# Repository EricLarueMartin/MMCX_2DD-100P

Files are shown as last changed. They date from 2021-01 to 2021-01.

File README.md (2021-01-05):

# MMCX_2DD-100P
Adapter between MMCX connectors to a 2DD 100 pin connector for Gretina cards

Requires two PCBs on 47 mil board, one for even channel and one for odd channels.
MMCX_2DD-100P_Even.zip and MMCX_2DD-100P_Odd.zip

Uses MMCX connectors: MOLEX 0734150961

The other connector is a double density 100 pin DSub connector: ITT Cannon 2DD-100PF0

The pins for the connector are 031-9540-015

Any MMCX plug can connector to the adapter, such as MOLEX 0734150970

The connector housing is in three pieces, two half shells and a spacer that goes between them. 
The two half shells are made of two material so that channel labels and the UNC logo are visible. This is all contained in: HousingLogoLabeled.2mf

The boards will be mounted at and angle, and the pins need to be soldered on first. A jig is recommended to insert the board without bending the pins:
InsertionGuideA.stl and InsertionGuideB.stl

To solder the pins in the correct position a connector with the holes drilled so the pins don't get stuck was used previously. Printing a jig for the pins from 2DD-100P.ipt should also work, but verify the hole spacing first as I think it was slightly off.

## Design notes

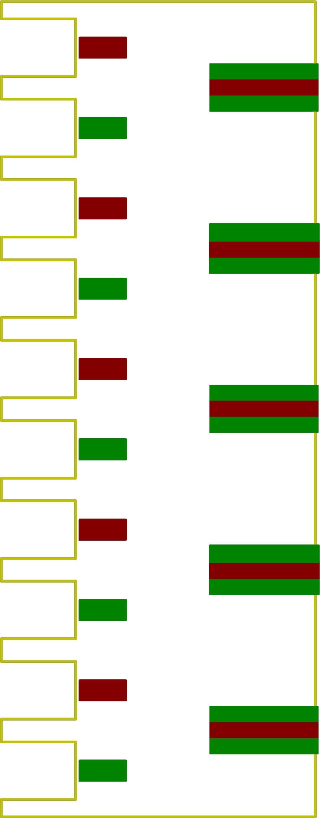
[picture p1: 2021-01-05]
MMCX_2DD-100P_Odd.png

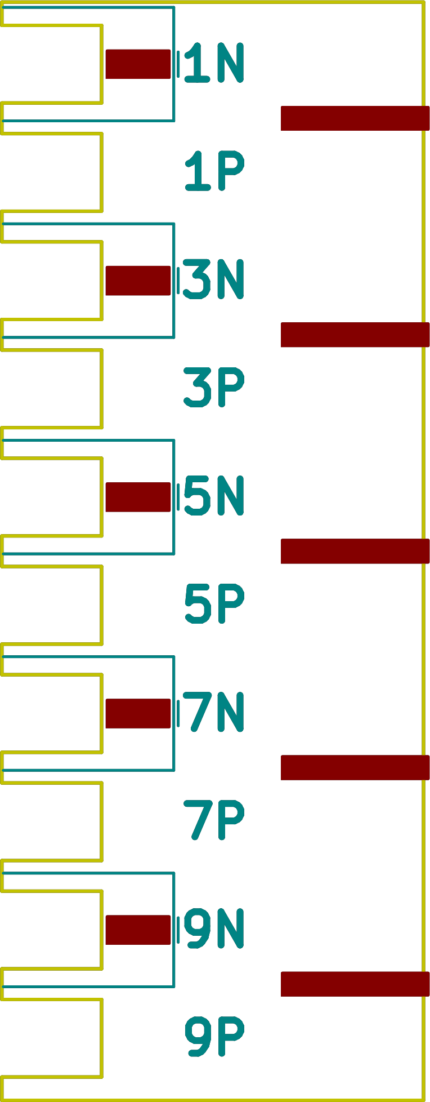
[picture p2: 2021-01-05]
MMCX_2DD-100P_Odd_Front.png

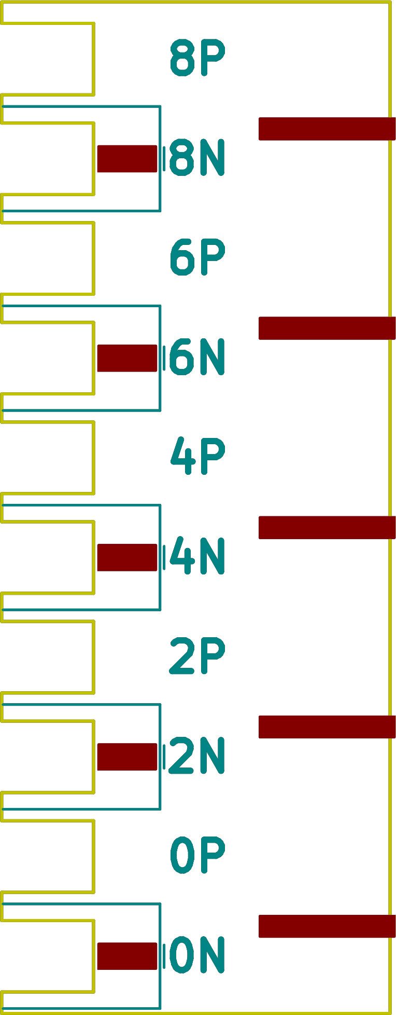
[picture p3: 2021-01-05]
MMCX_2DD-100P_Even_Front.png

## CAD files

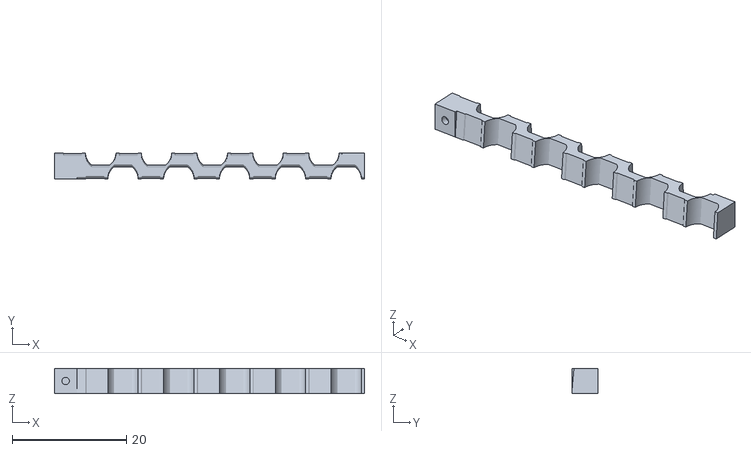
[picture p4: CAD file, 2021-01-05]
HousingSpacer.stl
54.2 x 4.63 x 4.41

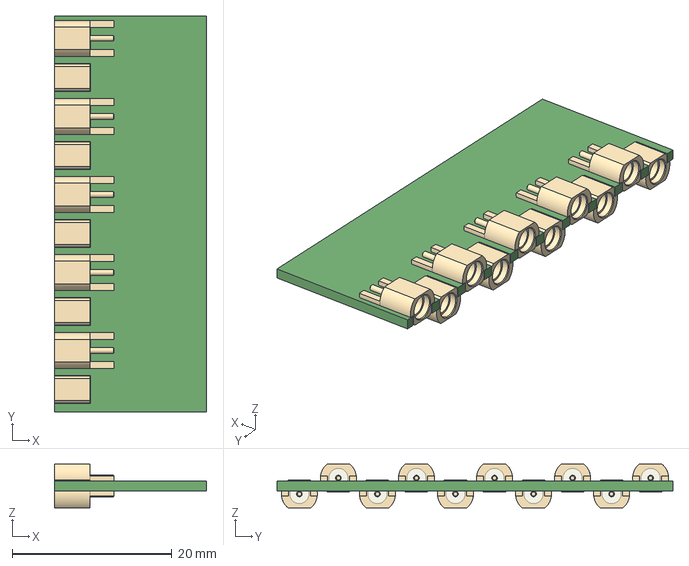
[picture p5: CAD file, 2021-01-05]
MMCX_2DD-100P_Odd.step
19.0 x 49.5 x 5.49 mm

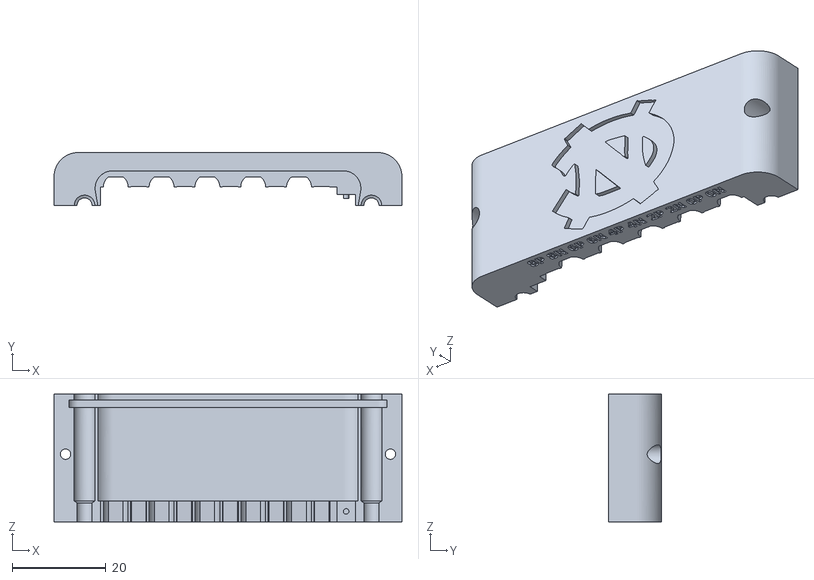
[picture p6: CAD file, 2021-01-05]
HousingEvenLogoLabeled.stl
74.1 x 11.3 x 27.2

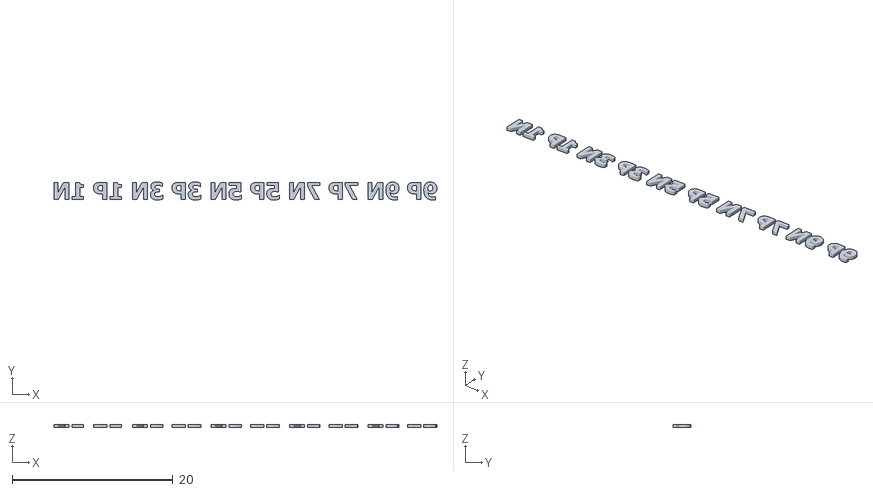
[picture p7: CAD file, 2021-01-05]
HousingOddLabels.stl
47.6 x 2.25 x 0.4

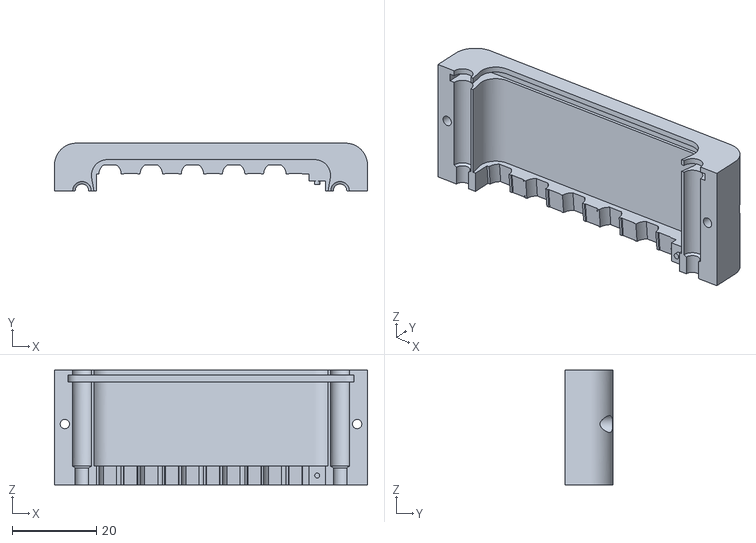
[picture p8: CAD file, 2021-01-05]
HousingBLogo.stl
74.1 x 11.3 x 27.2

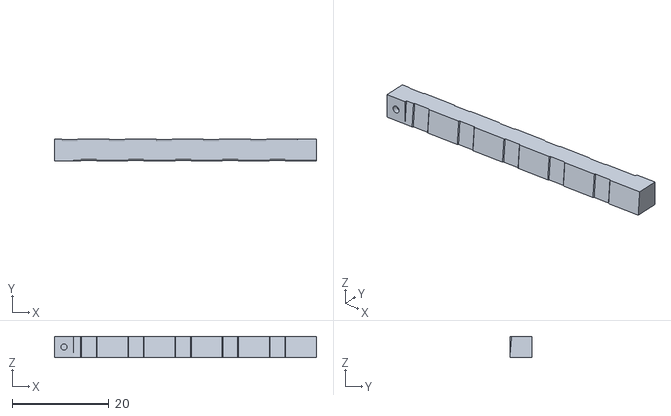
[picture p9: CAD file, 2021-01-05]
HousingSingleEndedALogo.stl
54.2 x 4.63 x 4.41

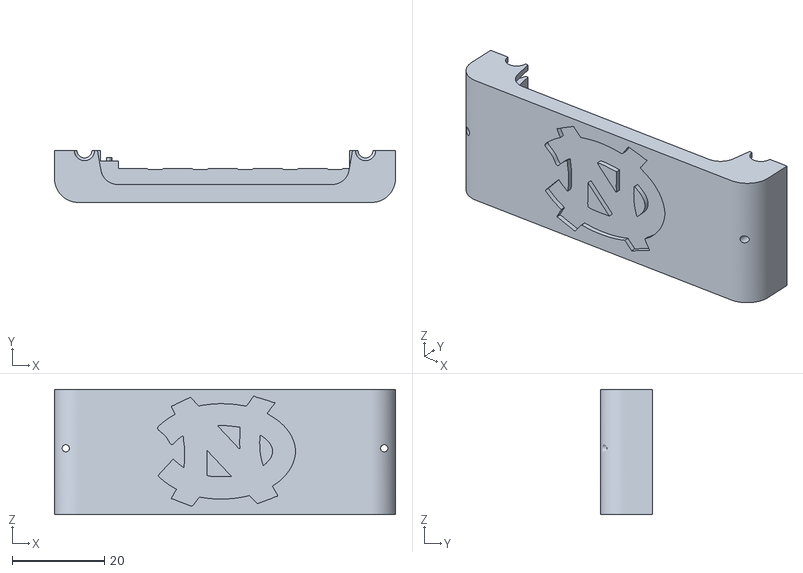
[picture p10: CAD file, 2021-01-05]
HousingSingleEndedCLogo.stl
74.1 x 11.3 x 27.2

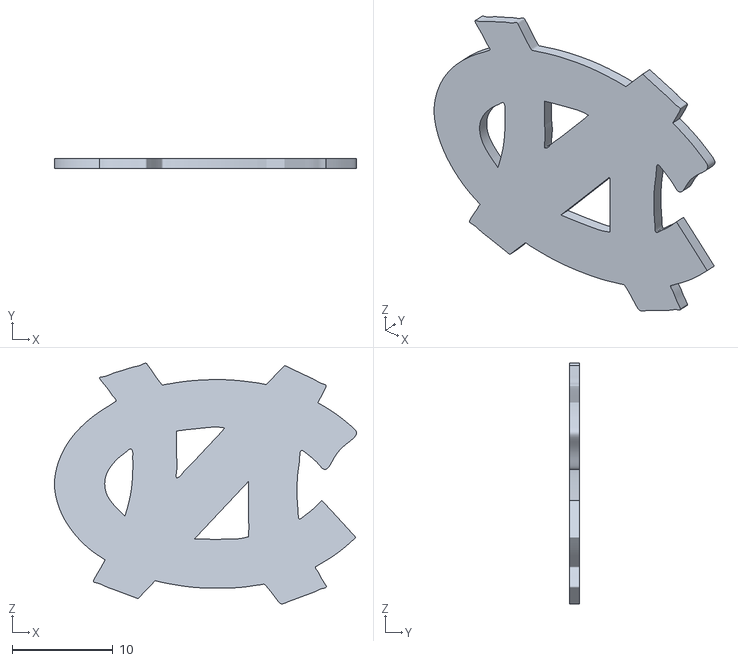
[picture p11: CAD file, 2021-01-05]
LogoB.stl
30.0 x 1.00 x 23.9

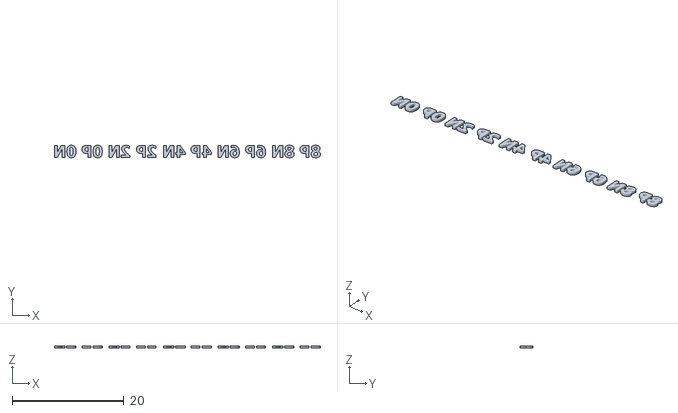
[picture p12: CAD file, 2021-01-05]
HousingEvenLabels.stl
47.6 x 2.26 x 0.4

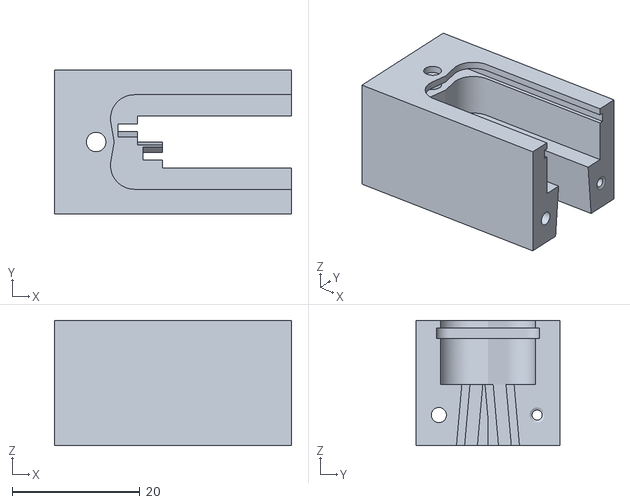
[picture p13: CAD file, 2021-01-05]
InsertionGuideB.stl
37.1 x 22.6 x 19.6

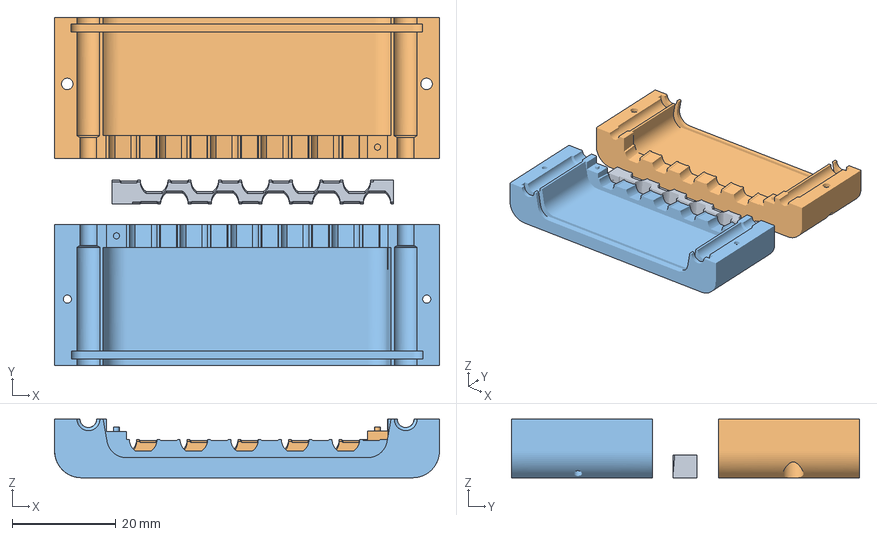
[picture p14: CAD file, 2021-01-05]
HousingLogoLabeled.3mf
74.2 x 67.0 x 11.3 mm
HousingSpacer.stl
HousingEvenLabels.stl
HousingOddLabels.stl

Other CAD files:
MMCX_2DD-100P_Even.step
HousingCLogo.stl
HousingA.stl
MMCX_2DD-100P.step
HousingSingleEndedBLogo.stl
HousingOddLogoLabeled.stl
InsertionGuideA.stl
2DD-100P.ipt
734151251.ipt
734151251.stp
HalfInterlockBox.ipt
HousingLabels.ipt
HousingLogo.ipt
HousingLogoPositive.ipt
HousingSingleEnded.ipt
HousingSingleEndedLogo.ipt
InsertionGuide.ipt
InsertionGuideOneConnected.ipt
LogoC.stl
MMCX_2DD-100P_All.iam
MMCX_2DD-100P_Even.iam
MMCX_2DD-100P_Guide.iam
MMCX_2DD-100P_Odd.iam
MMCX_Molex_73415-0961_Horizontal.iam
OldVersions/2DD-100P.0004.ipt
OldVersions/734151251.0001.ipt
OldVersions/Housing.0009.ipt
OldVersions/HousingLabels.0001.ipt
OldVersions/HousingLogo.0007.ipt
OldVersions/HousingLogoPositive.0002.ipt
OldVersions/HousingSingleEnded.0002.ipt
OldVersions/HousingSingleEndedLogo.0002.ipt
OldVersions/InsertionGuide.0003.ipt
OldVersions/MMCX_2DD-100P.0010.iam
OldVersions/MMCX_2DD-100P_All.0025.iam
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

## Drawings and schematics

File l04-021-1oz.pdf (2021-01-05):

## Multilayer PWB Construction Sheet

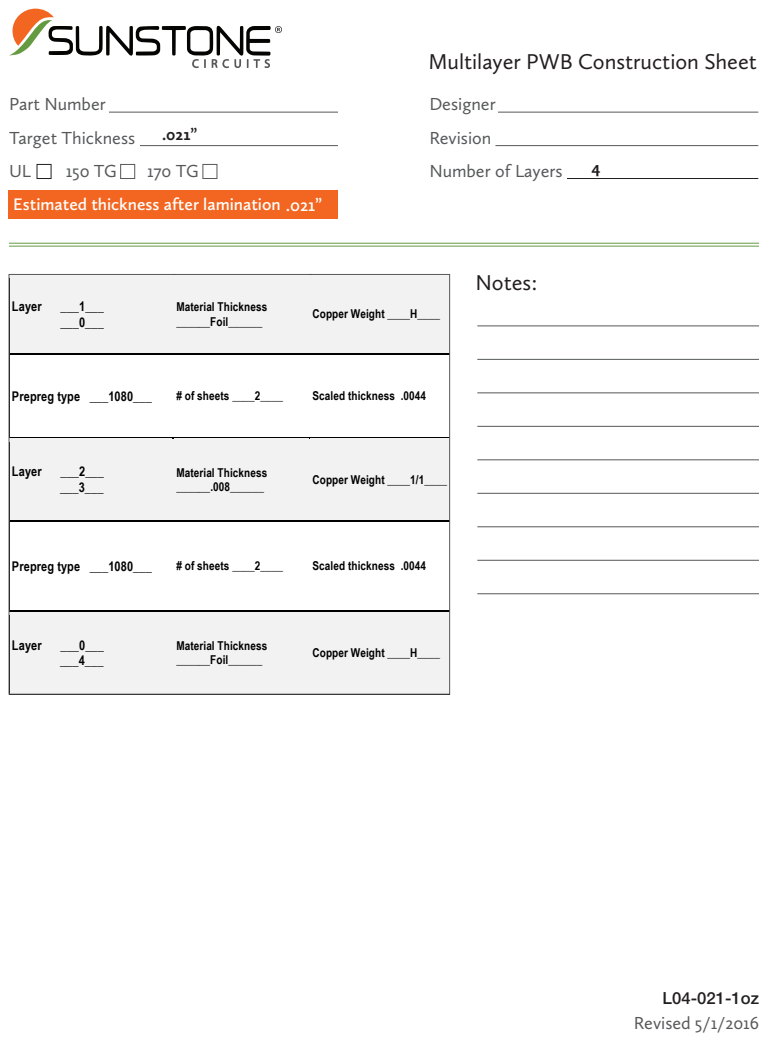
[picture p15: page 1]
Notes:; Revised 5/1/2016; Layer ___1___ ___0___; Material Thickness; ______Foil______; Copper Weight ____H____; Prepreg type ___1080___; # of sheets ____2____; Scaled thickness .0044; Layer ___2___ ___3___; Copper Weight ____1/1____; Layer ___0___ ___4___

Part Number
Target Thickness
Estimated thickness after lamination

Designer
Revision
Number of Layers

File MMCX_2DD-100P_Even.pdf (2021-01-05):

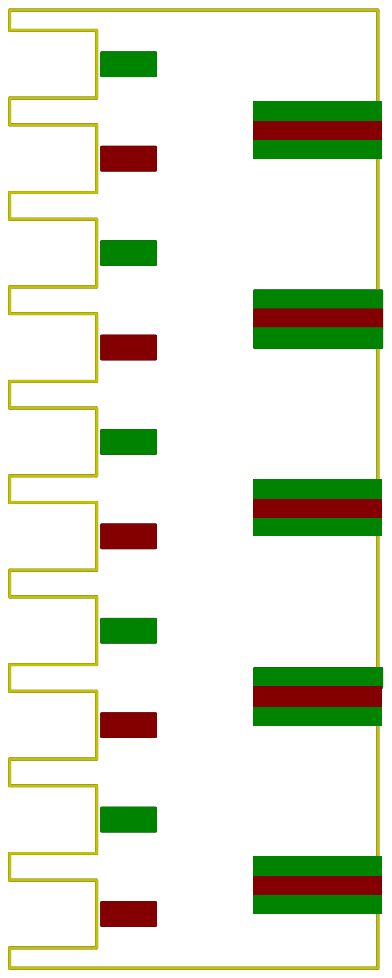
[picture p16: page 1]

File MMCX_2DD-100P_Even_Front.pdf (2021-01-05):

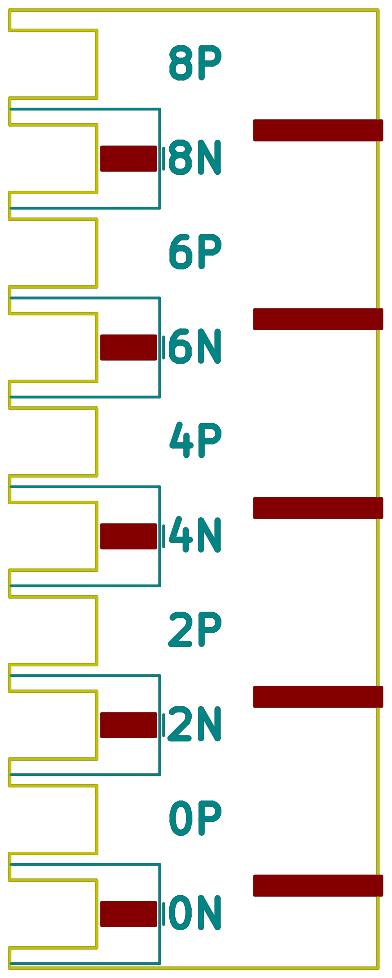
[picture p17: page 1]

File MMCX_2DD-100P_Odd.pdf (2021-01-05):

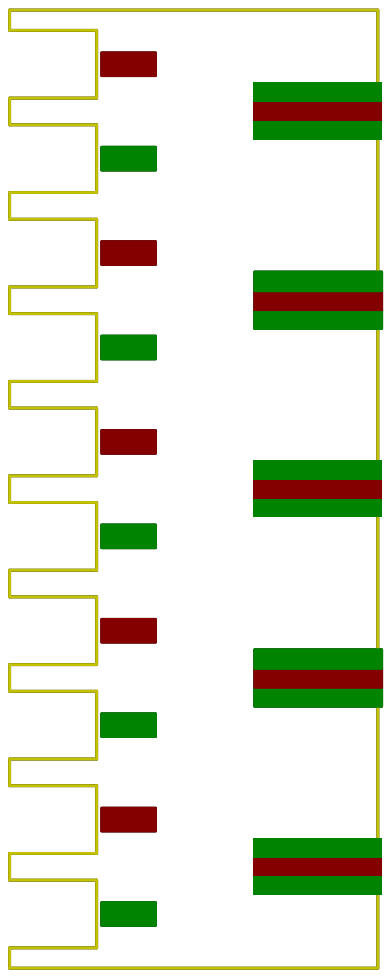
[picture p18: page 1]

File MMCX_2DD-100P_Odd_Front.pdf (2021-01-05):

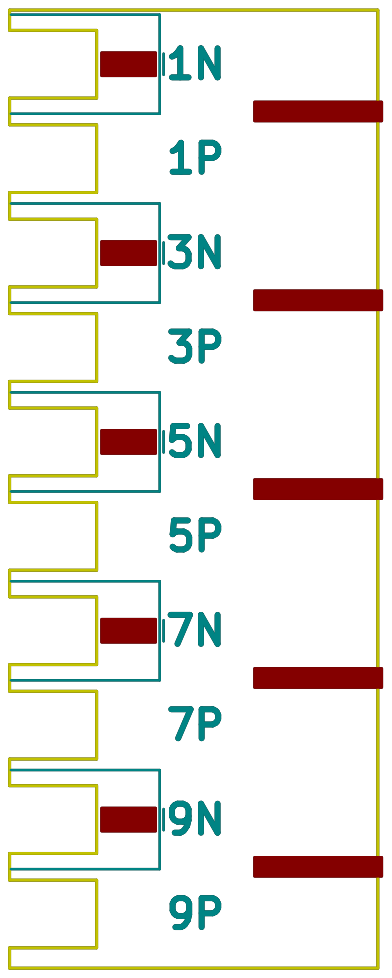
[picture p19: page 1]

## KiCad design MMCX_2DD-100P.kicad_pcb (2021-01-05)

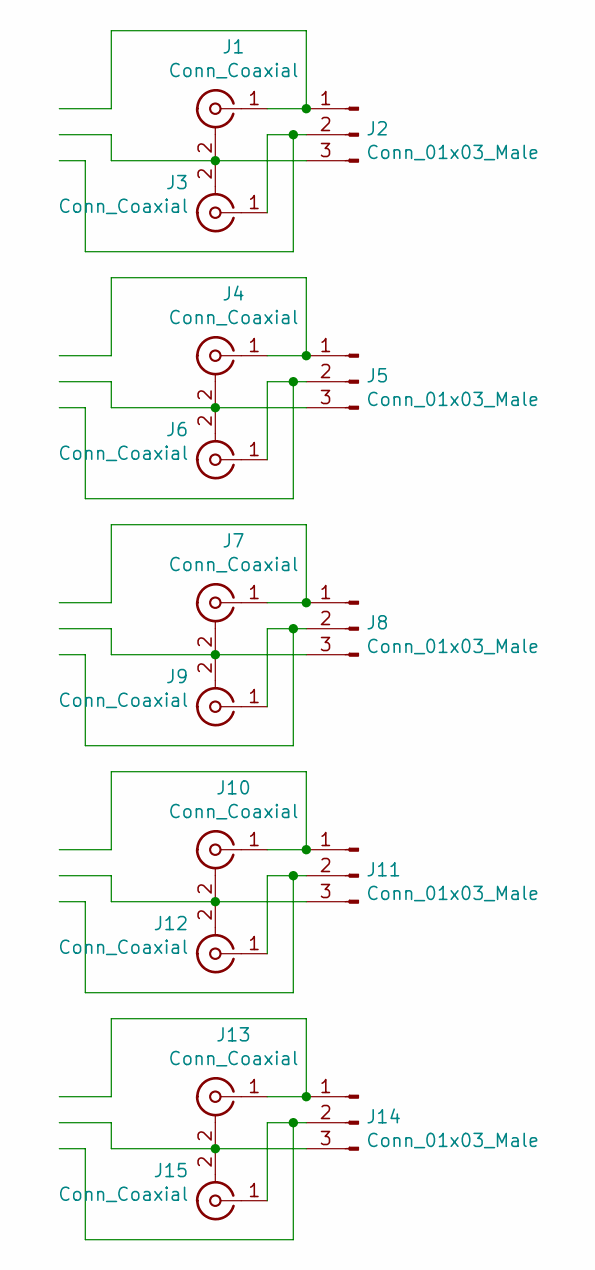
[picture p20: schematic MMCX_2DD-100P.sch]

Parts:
J1, J3, J4, J6, J7, J9, J10, J12, J13, J15: Conn_Coaxial; MMCX_EndLaunch_20mil_50ohm
J2, J5, J8, J11, J14: Conn_01x03_Male; 2xCoax_to_2DD

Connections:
unnamed: J1.1 (In), J2.1
unnamed: J1.2 (Ext), J2.3, J3.2 (Ext)
unnamed: J2.2, J3.1 (In)
unnamed: J4.1 (In), J5.1
unnamed: J4.2 (Ext), J5.3, J6.2 (Ext)
unnamed: J5.2, J6.1 (In)
unnamed: J7.1 (In), J8.1
unnamed: J7.2 (Ext), J8.3, J9.2 (Ext)
unnamed: J8.2, J9.1 (In)
unnamed: J10.1 (In), J11.1
unnamed: J10.2 (Ext), J11.3, J12.2 (Ext)
unnamed: J11.2, J12.1 (In)
unnamed: J13.1 (In), J14.1
unnamed: J13.2 (Ext), J14.3, J15.2 (Ext)
unnamed: J14.2, J15.1 (In)

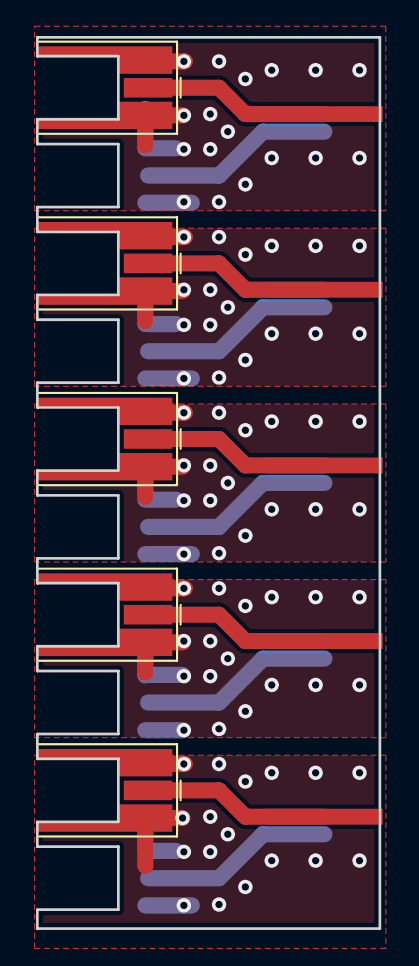
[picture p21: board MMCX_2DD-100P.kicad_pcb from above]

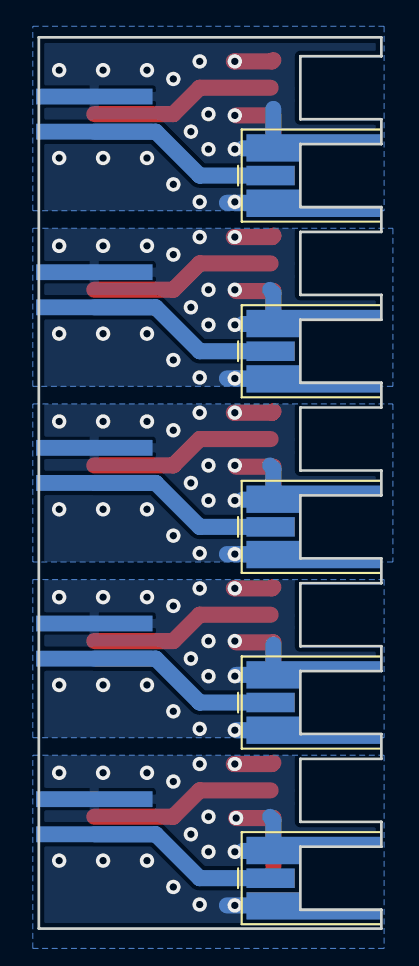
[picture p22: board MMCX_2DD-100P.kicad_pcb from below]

Board: 2 copper layers, 19.0 x 49.5 mm, 15 parts (10 on the bottom side), 15 nets.
